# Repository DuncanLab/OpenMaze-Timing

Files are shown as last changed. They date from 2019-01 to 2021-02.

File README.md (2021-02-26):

# OpenMaze Timing Library

This repository supports the main [OpenMaze](https://github.com/DuncanLab/OpenMaze) repository. 
The purpose of this repo is to detect and analyze timing discrepancies in between when OpenMaze displays an arbitrary trial on screen versus when the output file 'thinks' that a certain action happened. This was achieved by using a Raspberry Pi as a third party computer against the machine that OpenMaze was running on. 

In this repository you will find: 
* schematics for 3D printing your own Raspberry Pi sensor housing which adheres to the screen of the computer running OpenMaze.
* Python code that creates log files from monitoring the OpenMaze software through the Raspberry Pi.
* R code for conducting analysis on these output files.

## Getting Started

These instructions will get you a copy of the project up and running on your local machine for development and testing purposes.

### Prerequisites

What things you need to get the project up and running: 

1. A Raspberry Pi with a photodiode sensor, a sound sensor, and a button. 
2. Python configured on the Raspberry Pi. (This should already be done, just make sure you have Python 3)
3. [R](https://www.r-project.org/) installed on the machine with which you plan to do analysis with. 

## Hardware Set Up

For a more detailed explanation of the hardware set up necessary for this project, please see the documentation [here](https://github.com/DuncanLab/OpenMaze-Timing/wiki/Raspberry-Pi-Set-Up). A breif overview is written below. 

After acquiring the needed sensors, use the 3D models in `/3D_prints` to create housings for your sound and light sensors. This is especially important for the light sensor as the housing blocks out irrelevant light that could lead to innacurate results.  

Next, hook up the button, sound sensor, and light sensor to your Raspberry Pi. The goal is to build a circuit structure that looks like the following: 

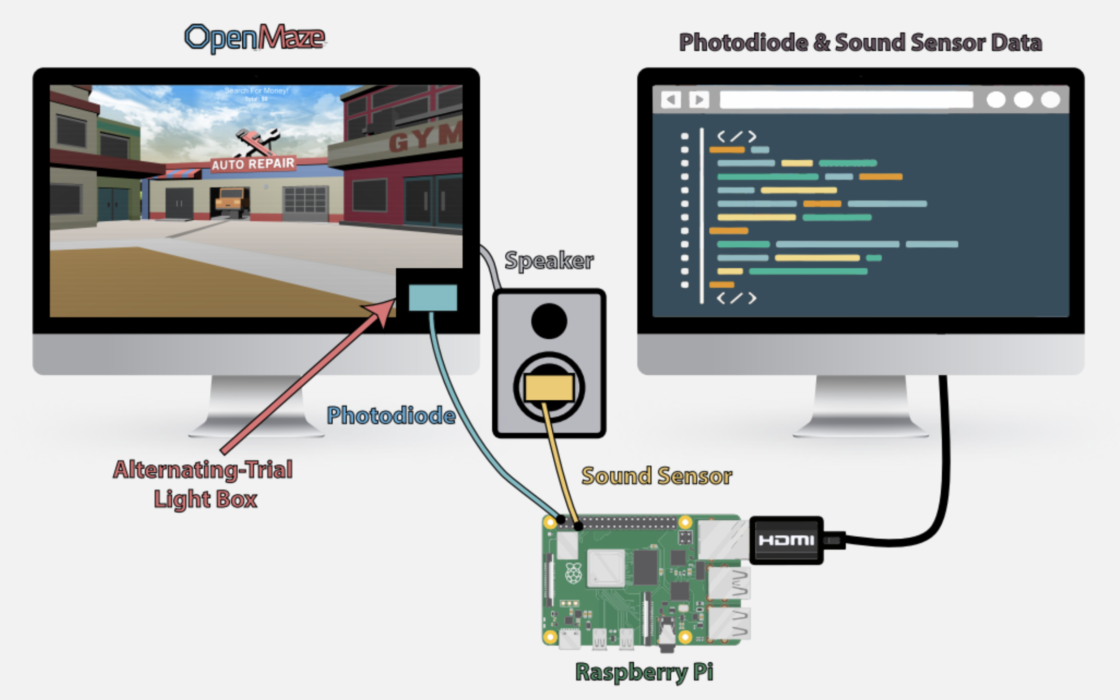
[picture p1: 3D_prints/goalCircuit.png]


You can use whichever inputs you prefer, but the current code places sensors at the following pins: 

```
GPIO.setup(4, GPIO.IN) # photo sensor IN at pin 4
GPIO.setup(18, GPIO.IN) # sound sensor IN at pin 18
GPIO.setup(26, GPIO.IN, pull_up_down=GPIO.PUD_UP) # button input IN at pin 26
```

The last step is to attach the light sensor to the bottom right of the computer running OpenMaze. Double-sided tape is a great option, but you can use alternatives if needed.

### Installing

Begin by cloning this repository onto your Raspberry Pi and installing the following Python packages onto the Raspberry Pi. 

```
pip install pandas
pip install pygame
```

Next, clone this repository on the machine that you will be using for data analysis and make sure that you have R installed.

### Recording Data

Now that you have everything set up, the process for data collection and analysis is as follows. 

1. Make sure that OpenMaze is set up correctly with the alternating black square in the bottom right corner turned on. You can learn how to do this [here](https://github.com/DuncanLab/OpenMaze-Timing/wiki/OpenMaze-Configuration).
2. Run the Python script on the Raspberry Pi after attaching the light.
3. When you are ready, press the input button on the Raspberry Pi and the spacebar on the OpenMaze set up simultaneously to begin recording with the Raspberry Pi. (Note: perfect syncrony is not necessary for accurate results as between-trial time is the measured metric, it just makes things simpler when viewing the data)
4. When you have finished running your test OpenMaze configuration file, simply click the Raspberry Pi input button again and it will stop recording data and output a spreadsheet in `.xlsx` format. 

### Running Analysis: 

Running the analysis is quite straightforward, simply run the R script also included in the repo and make sure that it is pointing to the right `.xlsx` spreadsheets that you collected in the previous step. The goal of this script is to identify scientifically relevant lag in the Unity system depending on which environments are being used. 

Feel free to add any additional data analysis that you need. We also recommend that you record test outputs with all of the environments that you plan on using for experimentation, as lag time differs depending on the elements in your scene. 

## Contributing

Please read our [contribution page](https://github.com/DuncanLab/OpenMaze-Timing/wiki/Contributing) for details on the process for submitting pull requests to us.

## Versioning

We use [SemVer](http://semver.org/) for versioning.

## Authors

* **Alex Gordienko** - *Initial work* - [Website](http://alexgordienko.com)
* **Kyle Nealy** - *Contributor* - [GitHub](https://github.com/kbnealy)

## License

This project is licensed under the MIT License.

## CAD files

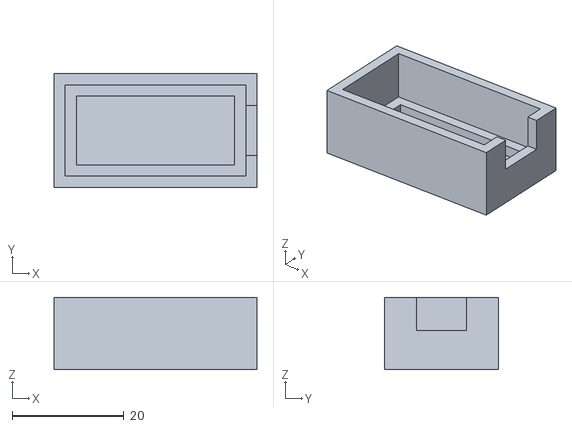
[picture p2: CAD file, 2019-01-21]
3D_prints/SoundBody.stl
36.4 x 20.4 x 13.0

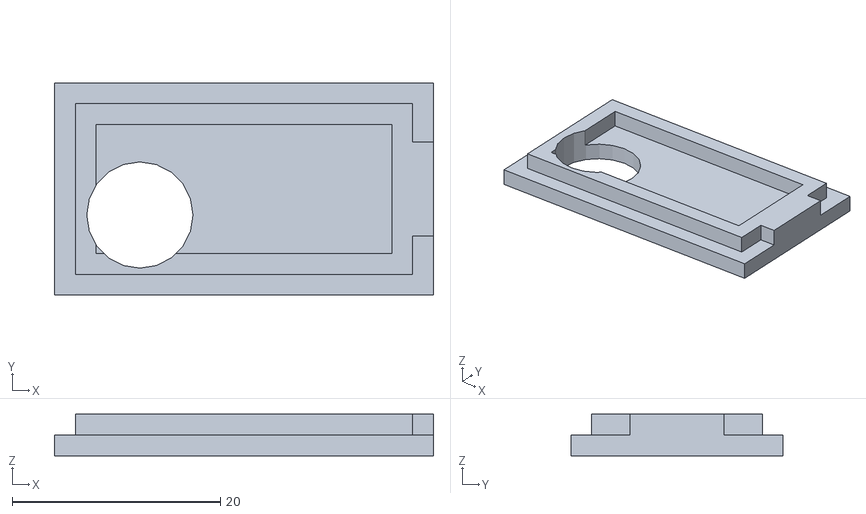
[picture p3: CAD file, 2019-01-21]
3D_prints/Soundlid.stl
36.4 x 20.4 x 4.00

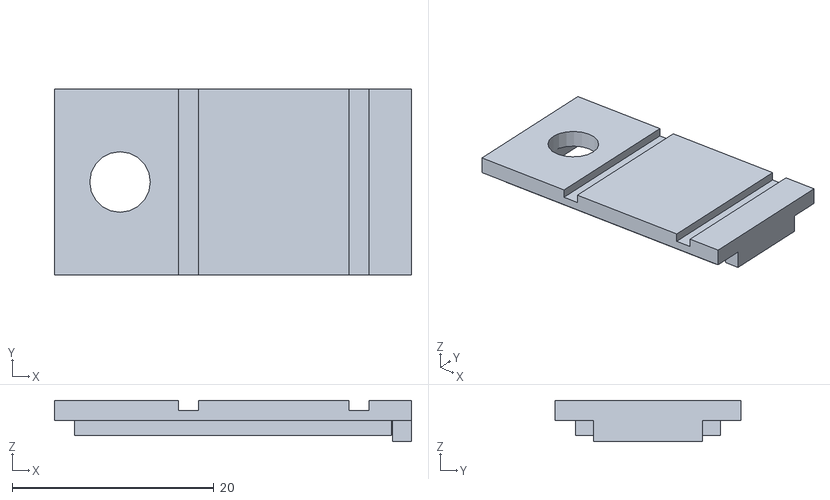
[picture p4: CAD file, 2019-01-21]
3D_prints/Photodiode Lid.stl
35.4 x 18.4 x 4.10

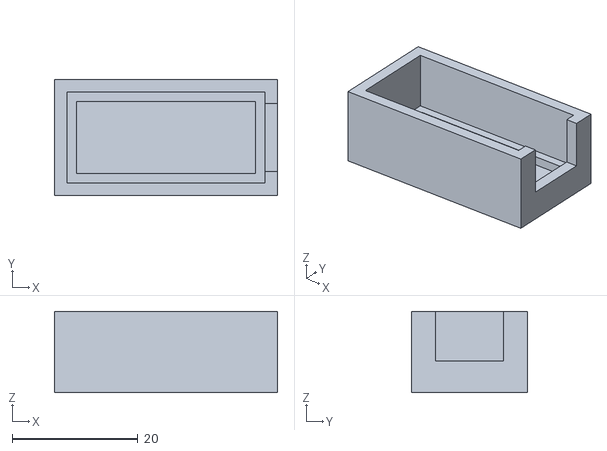
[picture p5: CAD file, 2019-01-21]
3D_prints/Photodiode Body.stl
35.4 x 18.4 x 12.9

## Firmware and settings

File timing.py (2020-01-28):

import RPi.GPIO as GPIO
import time
import threading # for threading to ensure time consistency
import datetime
from pandas import DataFrame # used for xlsx generation
import pygame # for keypress detection and initial syncronization
import sys # for termination of program

# Configure sensor inputs from Raspberry pi
GPIO.setwarnings(False)
GPIO.setmode(GPIO.BCM)
GPIO.setup(4, GPIO.IN) # photo sensor IN at pin 4
GPIO.setup(18, GPIO.IN) # sound sensor IN at pin 18
GPIO.setup(26, GPIO.IN, pull_up_down=GPIO.PUD_UP) # button input IN at pin 26

class Timing:
    '''
    Overarching class containing all timing-relevant functions.

    The purpose of this class is to facilitate accurate (to 10
    milliseconds) timing of certain events for OpenMaze
    (ie when a new trial starts and a new screen appears in
    front of the user, is Unity reporting the same information
    as what is actually going on?)

    Three basic sensors are used: a photo light sensor and a sound
    sensor are leveraged to trigger timing events between the
    experiment running in Unity and the raspberry pi. A simple
    switch is used to determine when to start and stop the
    experiment. 
    
    '''
        
    def __init__(self, startTime):
        '''
        Initialize class with current time and store original
        time. Also initialize arrays to store data for sensor
        fire events and corresponding times.

        Finally, output current time and state that experiment
        has loading and awaiting start. 
        '''
        self.startTime = startTime # set time var to init time
        self.lightSensorArray = [] # init array of all data from light sensor
        self.soundSensorArray = [] # init array of all data from sound sensor
        self.timeDataArray = [] # init array of all captured time data
        self.experimentStart = False # Bool to know if button has been clicked. 

        print(self.startTime)
        print('Experiment has loaded, awaiting button press to start timing.')
        
    def printSensorStream(self):
        '''
        Basic function to print out a stream of sensor data to the
        console.

        Use for debugging light and sound sensors when getting set
        up. 
        '''
        while True:
            # flip photo sensor value for consistency with sounds sensor
            print(int(not GPIO.input(4)), GPIO.input(18))

    def sensorDataAndTime(self):
        '''
        Function prints out sensor data as
        (photo / sound / time in milliseconds since
        start time).

        Use to test sensor and time integration as a stream
        of detectable outputs.
        '''
        # open a new thread and report sensor data every x seconds
        threading.Timer(0.1000, self.sensorDataAndTime).start()
        print(str(int(not GPIO.input(4))) +
              '/' + str(GPIO.input(18)) +
              '/' + str(datetime.datetime.now()-self.startTime))

    def concatDataToArray(self, lightSensorInput, soundSensorInput, currentTime):
        '''
        Add line of processed data from sensors and time to appropriate
        arrays.

        This function exists in order to prep all sensor data to be placed
        into a xlsx file. A data stream of 'raw' data is also printed for
        experiment reference. 
        '''
        print('raw', lightSensorInput, soundSensorInput, str(currentTime-self.startTime))
        print('')
        
        return(self.lightSensorArray.append(lightSensorInput),
                self.soundSensorArray.append(soundSensorInput),
                self.timeDataArray.append(str(currentTime)))

    def toExcel(self):
        '''
        Convert all stored data from created arrays to excel
        file and export to local path.

        Time of file creation is appended to name for easy
        interpretation. 
        '''
        spread = DataFrame({'Light Sensor Input': self.lightSensorArray,
                            'Sound Sensor Input': self.soundSensorArray,
                            'Current Time': self.timeDataArray,
                            'Start Time': str(self.startTime)
                            })
        print(spread) # display spread output before conversion. 
        spread.to_excel('config_10_timing_output.xlsx', sheet_name='timingSheet', index=False)
       
    def lightEdge(self, pin):
        '''
        if the light sensor detects a change then event is fired to
        record data of all sensors and current time. 
        '''
        
        self.concatDataToArray(int(not GPIO.input(4)),
                                   GPIO.input(18),
                                   datetime.datetime.now())
        
    def soundEdge(self, pin):
        '''
        if the sound sensor detects a change then event is fired
        to add sound data to arrays, however sound data is represented
        with a '1' since experimentation found that the sound sensor
        would produce unpredictable results. 
        '''
        
        self.concatDataToArray( not GPIO.input(4), 1, datetime.datetime.now())

    def runTimingExperimentWithKeyboard(self):
        '''
        Initial function run to start sensor readings and syncronize unity
        game and raspberry pi.

        Once 's' key is pressed on an attached keyboard, timing experiment will
        start and output to a csv file.

        Function will also listen for 'f' key press to stop sensor detection
        and put all data into a xlsx file for output.

        DEPRECATED: experimentation showed that raspberry pi had trouble handling
        keyboard listeners and sensor listeners without incurring significant
        delays for when sensor data was reported. 
        '''

        pygame.init()
        pygame.display.set_mode((100,100))
        while True:
            for event in pygame.event.get():
                if event.type == pygame.QUIT:
                    pygame.quit()
                if event.type == pygame.KEYDOWN:
                    if event.key == pygame.K_s:
                        print('Experiment START. Data collection init.')

                        # Mark current time, save to var

                        # Begin sensor output and save to arrays w/ timestamps
                        self.detectSurroundings()

                         
                    if event.key == pygame.K_f:
                        print('Experiment END. xlsx file generating.')

                        # Stop sensor output
                        self.endDetectSurroundings()

                        # Push data arrays to xlsx file and output.

                        # Terminate program
        
    def detectSurroundings(self):
        '''
        initialize light and sound sensors to detect surrounding. 
        '''
        GPIO.add_event_detect(4, GPIO.BOTH, callback=self.lightEdge)
        GPIO.add_event_detect(18, GPIO.BOTH, callback=self.soundEdge)
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

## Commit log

2018-11-07 updates to sensor firing and xslx output
2018-11-13 troubleshooting with sound sensor output
2018-11-16 completed start and stop of experiment with button press. Ran into issue of lag due to multiple processes running at the same time.
    [timing.py]
2018-11-21 got experiment start and stop to work with minimal delay with external analog button. Next steps: add rest of data to arrays and package to csv on stop + clean up code for readability.
2018-11-22 recovered some missing documentation
    [timing.py]
2018-12-20 Add files via upload
    3D print files for photodiode and sound sensor.
    [Photodiode Body.stl, Photodiode Lid.stl, SoundBody.stl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]
2019-01-21 initial timing test file
    [2019-01-21 14:07:37.400455_timing_output.xlsx]
2019-01-25 first 5 config files tested.
    [config1_timing_output.xlsx, config2_timing_output.xlsx, config3_timing_output.xlsx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]
2019-01-28 added additional timing files
    [CONfig6_timing_output.xlsx, config10_timing_output.xlsx, config11_timing_output.xlsx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]
2020-01-28 removed output files, cleaned up directory, fixed some typos in the python file
    [2019-01-21 14:07:37.400455_timing_output.xlsx, CONfig6_timing_output.xlsx, Photodiode Body.stl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]
2020-08-18 Added timing data and analysis scripts
    Data and scripts for (1) collision data (2) framerate/positional data (3) Trial onset/time. OpenMaze data files are tagged with "OM" and Raspberry Pi data files are tagged with "RP".
    [CollisionOM.csv, CollisionRP.csv, TrialOM.csv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]
